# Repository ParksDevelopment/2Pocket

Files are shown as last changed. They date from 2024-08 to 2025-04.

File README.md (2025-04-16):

# 2Pocket

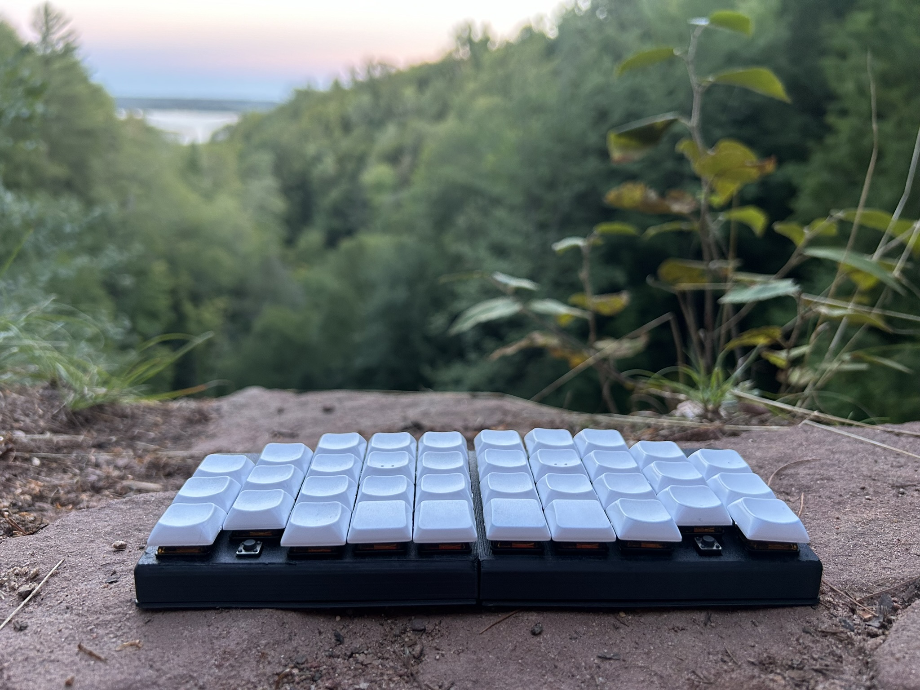
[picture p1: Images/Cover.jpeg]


[Introduction](#Introduction)

[Info and Production](#Production)

[PCB](#PCB)

[Firmware](#Firmware)

[Case](#Case)

[Overview](#Overview)

## Introduciton

The 2Pocket is a pocket keyboard originally created for the [Pocket Keyboard Design Contest](https://chrischrislolo.github.io/orthoLabLogs/pocket-keyboard-design-contest-00.html). As such it was designed to meet the criteria of the contest as closely as possible while still being a practical keyboard for daily use. The feature list of the 2Pocket is pretty fleshed out including:

- 36 Kailh Choc V1 Low Profile Hot swap sockets (Using [Sunset](https://lowprokb.ca/collections/switches/products/sunset-tactile-choc-switches) switches for all pictures)
- Bluetooth support between halves and computer
- Pedometer using a ADXL345 for step counting
- 2 additional 6 mm Push button switches used for bluetooth, step reporting, or any othe KMK key
- Full open source customizeable keymap in KMK. ZMK to be included soon
- 2 3.7V 1100 mAh batteries Charged through the USB C port on the back of each board
- Magnetic casing to make the board unibody for preference, saving space, or travel
- Small enough to fit in your pocket! (according to the contest which gives a 190mm x 76mm x 22mm bounding box with the 2Pocket coming in comfortably at 190mm x 74.8mm x 22mm)

The idea behind the board was to create something that you can put in your pocket, ie fitting the bounding box, but does not force you to make any compromises to your work flow. I work a full time job as an software engineer and use a 36 key layout called [Miryoku](https://github.com/manna-harbour/miryoku_kmk) so it was important to me above all else to fit that standard so 36 keys was a must for me. I am able to hit 85 words per minute on it in monkey type 60 tests which is slower than my peak on a normal keyboard of 100 but definetly far from unpractical. Another key requirement for me was bluetooth. If this would be a pocket board then I would need it to be easier to bring places than my normal keyboard. The size helps but keeping it wireless allows me to pick it up on the way out the door or throw it in my bag without any fear of not having the necessary parts to make it run. Finally I wanted to play into the pocket part of the challenge which lead to the on board ADXL345. If I plan on keeping the board in my pocket It is already in the prime position to track my steps, and by mapping a button press to output my number of steps on the screen I am able to quickly see where I am at on the given day or trip. It gives me a great reason to still carry the board around even if I am not sure it will come in handy. Its not as accurate as a smart watch or even a smartphone but it gets pretty close and I am continuing to improve the step counting algorithem and features.

## Production

I will briefly explain below how to reproduce the board as well as discuss improvements that could be made in the future on the project in each area so. The production of the board is reletively simple, but will require either a 3D printer or ordering the case parts through a provider. I also chose to solder some parts and order the board with other parts soldered on. If you have a soldering station I would recommend you do the same but you can choose whatever works best for you. Below is the parts list which does not inclued the pcb or the case which will be discussed later:

| Part Name  | Quantity | Solder by hand |
|---|---|---|
| Ceramic Capacitors 1uF| 4| NO|
| Tantalum Capacitors 10uF| 2| NO|
| ADXL345 | 2| NO|
| 1N4148 Diode | 38| NO|
| 4.7 k oHm Resistor | 4| NO|
| 2 pin Jst socket | 2| YES|
| 6 mm push button switches | 2| YES|
| Choc hotswap sockets | 36| YES|
| Xiao NRF52840 | 2| YES|
| EEMB Lithium Polymer Battery 3.7V 1100mAh | 2| DNA|

most of these the brand doesn't matter but the case is modeled to fit this specific battery so if you would like to use a different battery you need to make some modifications.

## PCB

The PCB has a footprint of 185mm x 71mm x 1.6mm which does not give a ton of room for the case but it is hard to scale it down much without giving up keys or making the wiring much more complicated. To order the case go to the PCB folder in this repo and then go to the production folder in there. that includes the gerber files as well as the BOM and POS files needed to order from jlcpbc. The original kicad project is there as well so if you need to regenerate the files that should be possible. the BOM will only inclued the parts I list as not soldered by hand. in addition double check the position of the ADXL345s. they should always be oriented so pin one is on the side closer to the Xiao board. Once the board is ordered just snap it in the middle and trim off any parts left over on the side. Then solder the remaining part on. 

I am pretty happy with the pcb but there are 2 big changes I would make:

1. I would wire the ncf pins on the xiao to the interupt pins on the adxl345. The ncf pins can act as extra gpio pins with some software changes and connecting them to the adxl345 would let me do things like shake to undo or stop any keystrokes if it detects the board has been knocked off. this stuff could still be done as is but I would need to check often and it would hurt the battery.
2. I could include a coulple mounting holes. I got by ok without them but some holes that are purely for helping connect it to the case would open up how you can design the case quite a bit.

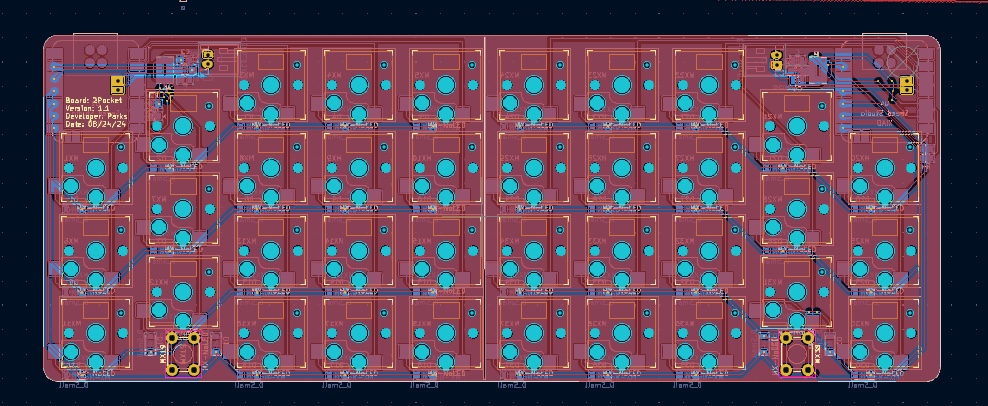
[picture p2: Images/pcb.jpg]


## Firmware

The firmware is written in KMK. To install it just follow the [getting started](https://kmkfw.io/Getting_Started/) guide on the KMK site. After getting circuit python and kmk installed you should then follow the [bluetooth guide](https://kmkfw.io/ble_hid/) just up to adding the adafruit bluetooth folder into your project. Once that is done you can go to this repo, go to firmware, go to kmk and replace your code.py with the one there then take the adxl345.py and drag it into the extensions folder. Currently the keymap is Miryoku modified which used colemak DH mod. Once all that is done you can edit the keymap to your liking using KC.STEPS to print out how many steps have been taken and KC.CLEARBT to disconnect and pair to a new bluetooth device. kmk bluetooth can be finicky so if you run into issues you can ask at the [zmk help forum](https://kmkfw.zulipchat.com/#recent).

There is a lot I would touch on with the firmware, like I want to flesh out the step counter to keep the number in memory between shutting off so you don't lose it if the battery dies but the number one thing I will add is zmk support. I tried to have this done for the entry date for the contest and am very close but am having trouble getting the adxl345 to interface with zmk. once that is done I will add the zmk firmware here. zmk handles bluetooth much better than kmk so that alone would be worth it. 

## Case

The case is printed in 4 parts and requires a couple parts after the fact. It is pretty bare bones without a lot of bells and whistles due to only having about 5 mm to work with at most. That said it is sturdy enough to go in your pocket and has no gaps save for the usbc port to prevent dust or other things from getting into the board from your pocket. The parts needed are in the table below. I am linking to the ones I used but anything with these dimensions will work. or you can edit the case to fit something else. (I have no idea how affiliated links work but nothing I link to in this page has any affiliation with me and I don't benifit from)

| Part Name  | Quantity | Link  |
|---|---|---|
| Magnets | 8| [Link](https://www.amazon.com/dp/B0936M3WPK?ref=ppx_yo2ov_dt_b_fed_asin_title)|
| M3 threaded inserts| 4| [Link](https://www.amazon.com/dp/B0BQJ6CRNJ?ref=ppx_yo2ov_dt_b_fed_asin_title)|
| M3 flat head screws. shorter the better | 4| [Link](https://www.amazon.com/HanTof-Countersunk-Machine-Wrenches-Threaded/dp/B0B9HWVV61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)|

The top of the case has 2 small holes on the side that is flat and would touch the other half of the keyboard. In both those holes insert the magnets so they are flush and then glue the backs of them around the hole on the inside of the case. Repeat of the other half and let sit.

The bottom half has One set of holes near the battery holder and one set on the other side of the case. The set on the side with the battery holder will hold the magnets. Put some glue at the back and then insert them. The other set of holes need the threaded inserts inside. I use a soldering iron with a M3 tip but you can use any method you would like. 

To combine everything put some keys in the top, push the pcb into the case so the keys go into the hot swap sockets. Then take the bottom, put the battery in the holder and connect it to the jst connector. Then put the bottom on, the magnets should line it all up. Finally screen in the m3 screws on the other side untill they are flush.

The case could be improved in a lot of areas. I have very limited experience with 3D modeling so I have no doubt it can be done much better. I would probably redesign it once I have mounting holes to screw in from the bottom so I don't have to sacrifice the sides so much just to allow for a connection. This is the first part I would do a complete overhaul on but for now it works well enough, keeping the board and battery secure while staying within the bounding box, barely.

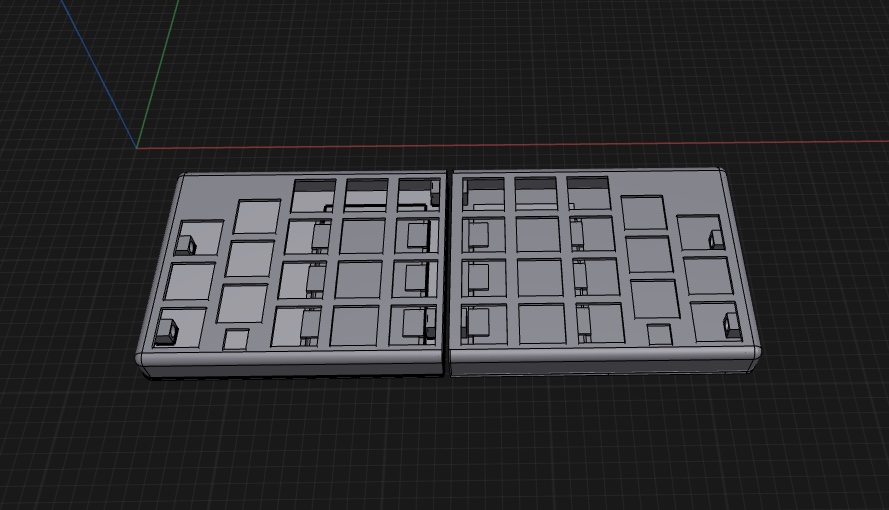
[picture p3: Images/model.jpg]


## Overview

Overall I am very happy with the board and think it fit the criteria of the contest while being a practical board for me to use. The extra gimmick of acting as a pedometer only adds to the charm and my enjoyment of bringing it out of the house. I am excited to keep interating on it in the future but know the board as it stands is fully functional and will be used as my daily driver for a couple days to prove that. I also want to thank Chris Lo aka sporewoh for putting on the contest. It was very fun to design the project fitting into a certain critera and being pushed to add gimmicks and functionality into such small size.

If you enjoyed or found and of the information helpful consider [Buying me a coffee](https://buymeacoffee.com/parks) to keep working on projects like this!

p.s. enjoy the [extra photos](https://photos.app.goo.gl/FVwNr18BBK3Yw1VW6) my wife took of the board on a hike



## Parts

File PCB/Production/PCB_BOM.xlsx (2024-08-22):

Comment | Designator | Footprint
4.7_Resistor | R3,R2,R1,R4 | R_0805_2012Metric
D_Small | D36,D8,D25,D27,D12,D1,D6,D9,D24,D38,D35,D20,D28,D19,D13,D23,D3,D17,D15,D34,D32,D18,D4,D21,D29,D16,D33,D30,D7,D37,D11,D2,D26,D22,D5,D10,D14,D31 | D_SOD-123
T491A106K016AT | C6,C3 | CP_EIA-3216-18_Kemet-A
.1uf_C | C5,C2,C4,C1 | C_0805_2012Metric
ADXL345 | U1,U3 | PQFN80P500X300X100-14N

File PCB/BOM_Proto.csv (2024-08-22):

Id | Designator | Footprint | Quantity | Designation | Supplier and ref
1 | MX12,MX6,MX15,MX31,MX27,MX5,MX11,MX29,MX16,MX2,MX10,MX30,MX34,MX3,MX21,MX20,MX7,MX32,MX13,MX35,MX33,MX25,MX14,MX1,MX8,MX37,MX28,MX9,MX23,MX36,MX17,MX18,MX4,MX24,MX22,MX26 | Kailh_socket_PG1350 | 36 | MX-NoLED
2 | MX19,MX38 | SW_PUSH_6mm | 2 | MX-NoLED
3 | D36,D8,D25,D27,D12,D1,D6,D9,D24,D38,D35,D20,D28,D19,D13,D23,D3,D17,D15,D34,D32,D18,D4,D21,D29,D16,D33,D30,D7,D37,D11,D2,D26,D22,D5,D10,D14,D31 | D_SOD-123 | 38 | D_Small
4 | J2,J1 | JST_PH_S2B-PH-K_1x02_P2.00mm_Horizontal | 2 | Conn_01x02
5 | C6,C3 | CP_EIA-3216-18_Kemet-A | 2 | C_Polarized_US
6 | C5,C2,C4,C1 | C_0805_2012Metric | 4 | C
7 | U1,U3 | PQFN80P500X300X100-14N | 2 | ADXL345
8 | U2,U4 | XIAO-nRF52840-Sense-14P-2.54-21X17.8MM | 2 | Seeed Studio XIAO nRF52840
9 | R3,R2,R1,R4 | R_0805_2012Metric | 4 | R

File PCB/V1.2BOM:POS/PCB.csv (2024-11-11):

Id | Designator | Footprint | Quantity | Designation | Supplier and ref
1 | MX12,MX6,MX15,MX31,MX27,MX5,MX11,MX29,MX16,MX2,MX10,MX30,MX34,MX3,MX21,MX20,MX7,MX32,MX13,MX35,MX33,MX25,MX14,MX1,MX8,MX37,MX28,MX9,MX23,MX36,MX17,MX18,MX4,MX24,MX22,MX26 | Kailh_socket_PG1350 | 36 | MX-NoLED
2 | MX19,MX38 | SW_PUSH_6mm | 2 | MX-NoLED
3 | J3,J4 | PinHeader_1x02_P2.54mm_Vertical | 2 | Conn_01x02
4 | D36,D8,D25,D27,D12,D1,D6,D9,D24,D38,D35,D20,D28,D19,D13,D23,D3,D17,D15,D34,D32,D18,D4,D21,D29,D16,D33,D30,D7,D37,D11,D2,D26,D22,D5,D10,D14,D31 | D_SOD-123 | 38 | D_Small
5 | J2,J1 | JST_PH_S2B-PH-K_1x02_P2.00mm_Horizontal | 2 | Conn_01x02
6 | C6,C3 | CP_EIA-3216-18_Kemet-A | 2 | C_Polarized_US
7 | D39 | D_SOD-123 | 1 | D_Schottky
8 | C5,C2,C4,C1 | C_0805_2012Metric | 4 | C
9 | U1,U3 | PQFN80P500X300X100-14N | 2 | ADXL345
10 | R3,R2,R1,R4 | R_0805_2012Metric | 4 | R
11 | U2,U4 | XIAO-nRF52840-Sense-14P-2.54-21X17.8MM | 2 | Seeed Studio XIAO nRF52840

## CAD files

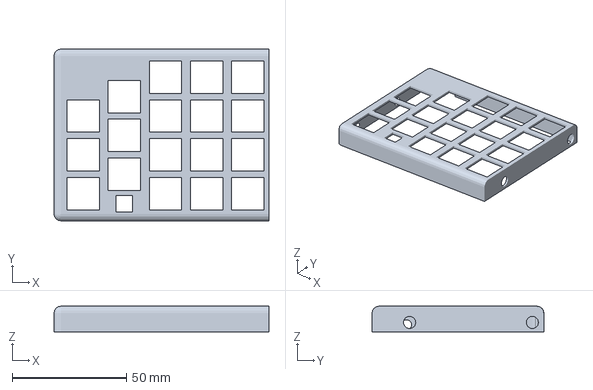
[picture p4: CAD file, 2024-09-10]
Case/Current Case/LeftTop.3mf
94.0 x 75.1 x 11.2 mm

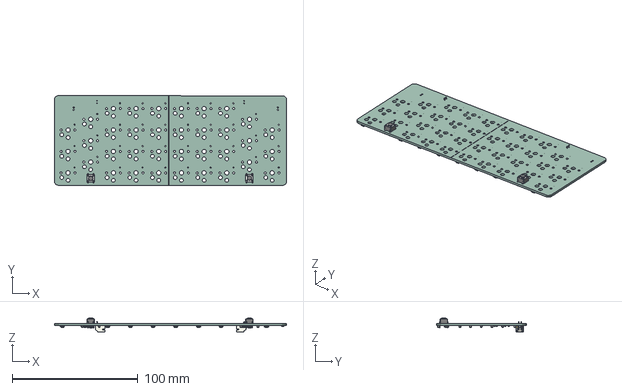
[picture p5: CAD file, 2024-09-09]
Case/PCB_Model.STEP
184.2 x 71.2 x 10.8 mm
PCB PCB

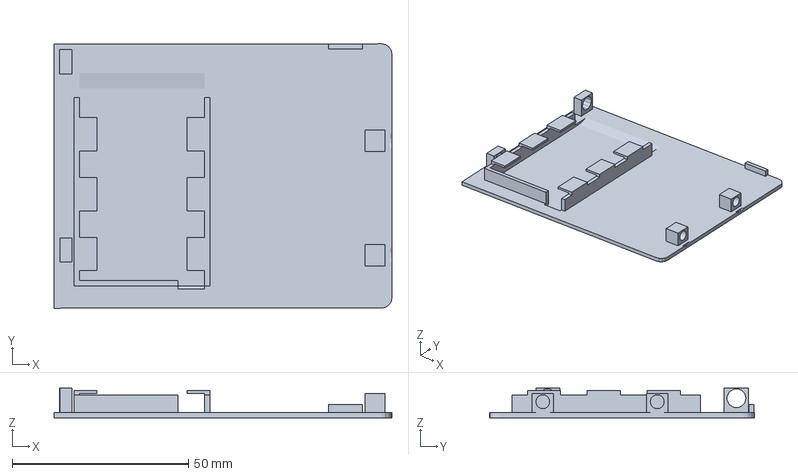
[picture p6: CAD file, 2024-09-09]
Case/Current Case/RightBottom.3mf
96.0 x 75.1 x 8.50 mm

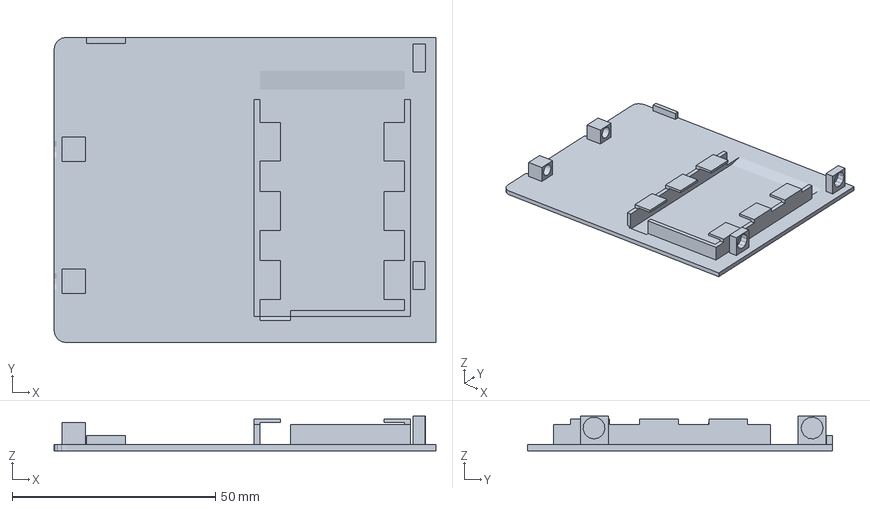
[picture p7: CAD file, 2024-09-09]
Case/Current Case/LeftBottom.3mf
94.0 x 75.1 x 8.50 mm

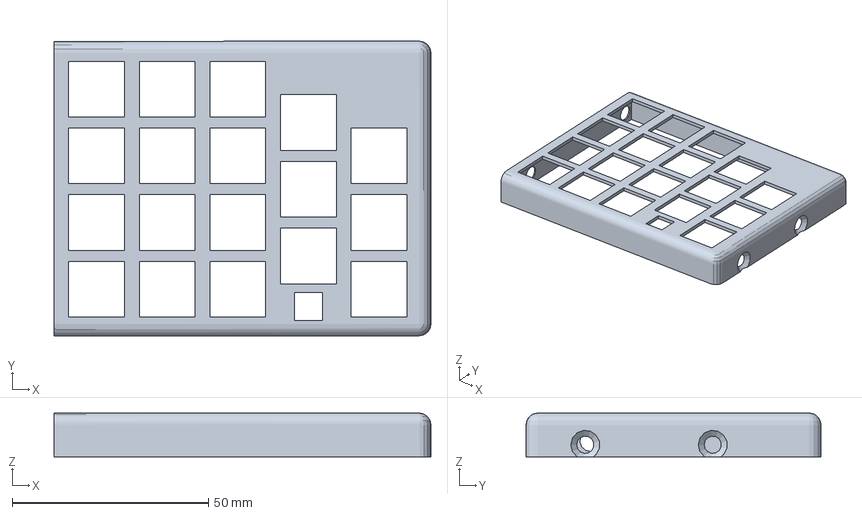
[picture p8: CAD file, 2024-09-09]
Case/Current Case/RightTop.3mf
96.1 x 75.1 x 11.2 mm

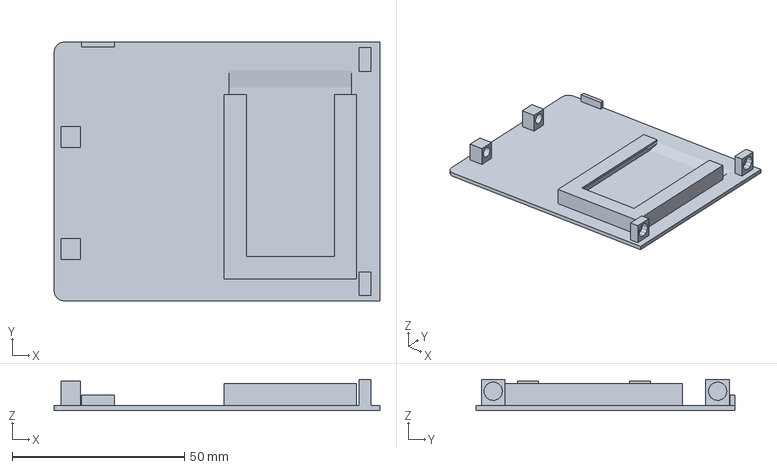
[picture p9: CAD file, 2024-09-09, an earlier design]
Case/Previous Case Revisions/Case_Bottom_4.3mf
94.5 x 75.1 x 9.00 mm

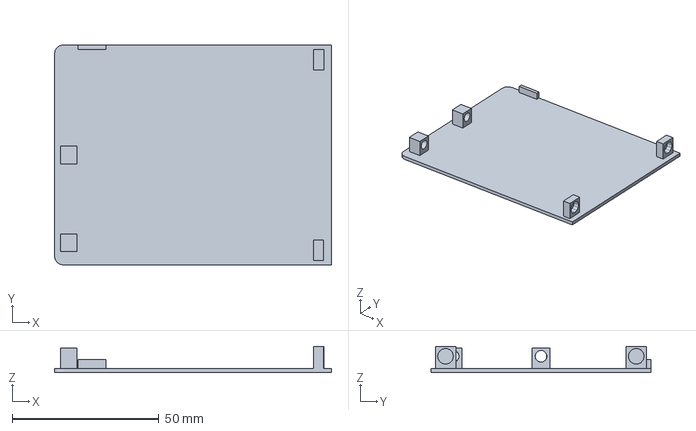
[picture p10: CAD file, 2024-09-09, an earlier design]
Case/Previous Case Revisions/Case_Bottom_3.3mf
94.5 x 75.1 x 9.00 mm

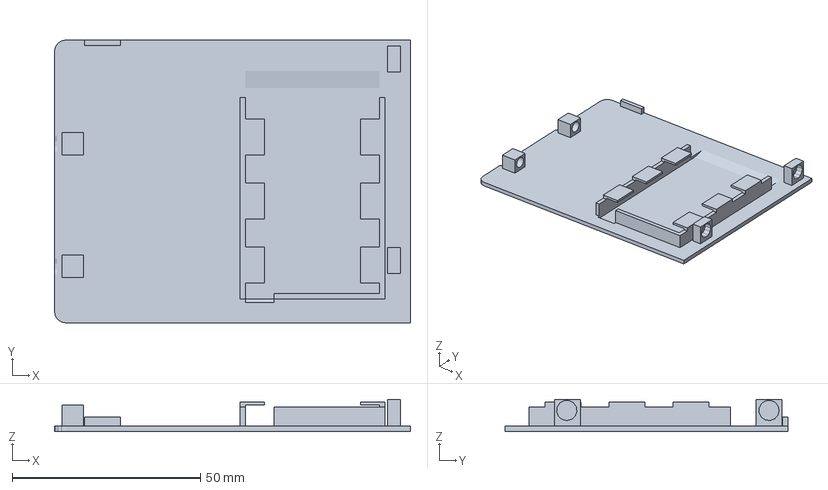
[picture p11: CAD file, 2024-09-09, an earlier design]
Case/Previous Case Revisions/Case_Bottom_6.3mf
94.5 x 75.1 x 8.50 mm

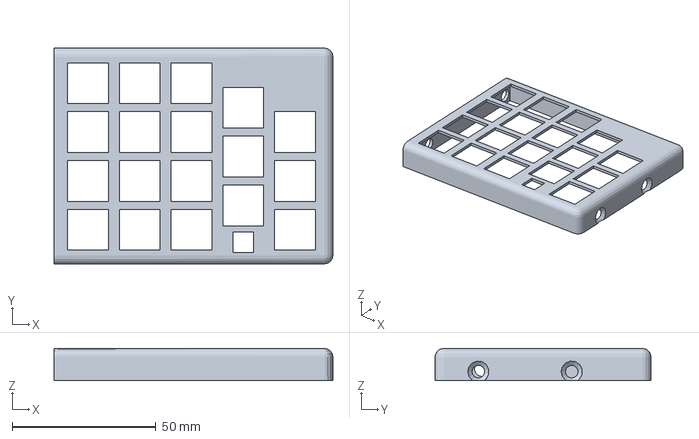
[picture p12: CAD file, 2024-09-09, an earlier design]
Case/Previous Case Revisions/Case_Right_1.3mf
97.1 x 75.1 x 11.2 mm

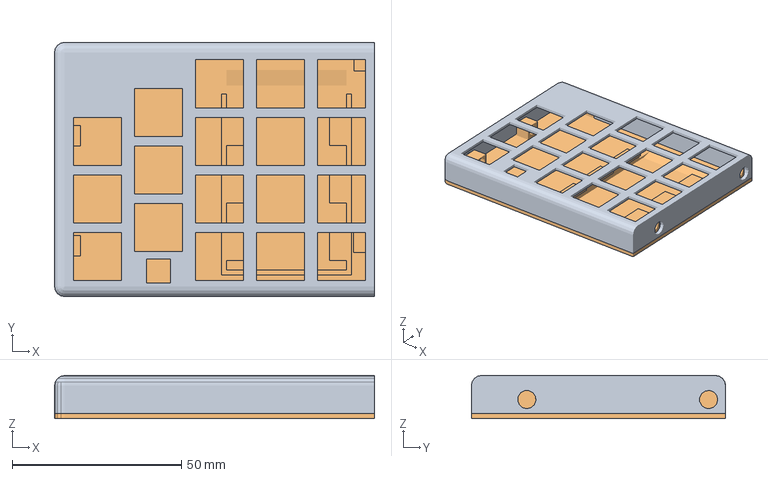
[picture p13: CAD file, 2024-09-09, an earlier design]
Case/Previous Case Revisions/Case_joined_1.3mf
94.5 x 75.1 x 12.7 mm

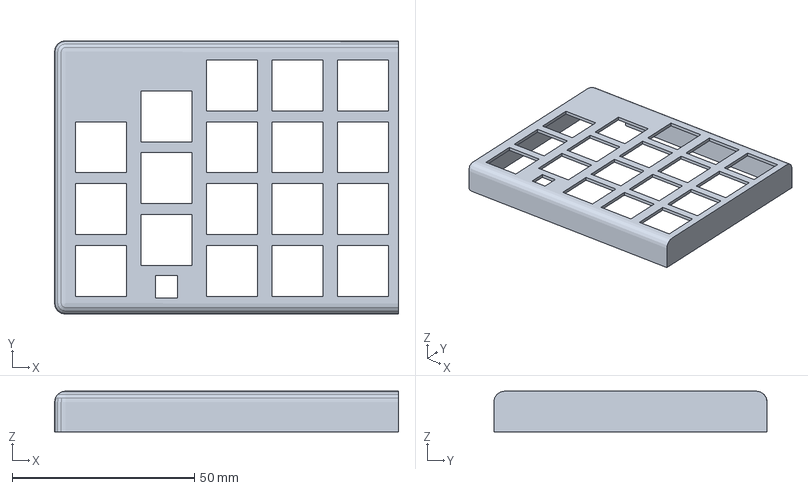
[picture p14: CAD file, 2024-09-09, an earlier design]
Case/Previous Case Revisions/Case_1.3mf
94.5 x 75.1 x 11.2 mm

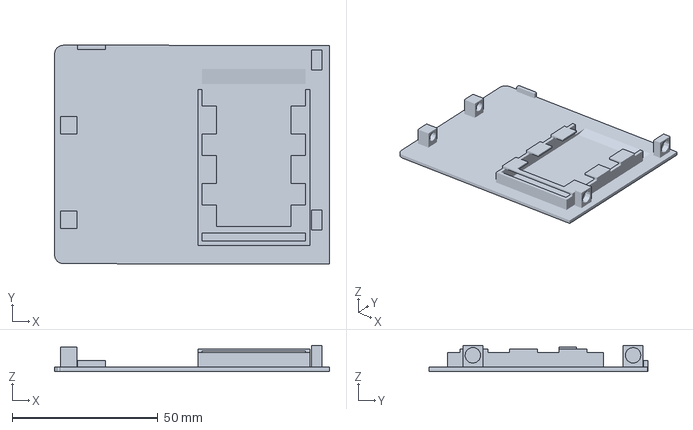
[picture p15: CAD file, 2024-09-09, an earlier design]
Case/Previous Case Revisions/Case_Bottom_5.3mf
94.5 x 75.1 x 9.00 mm

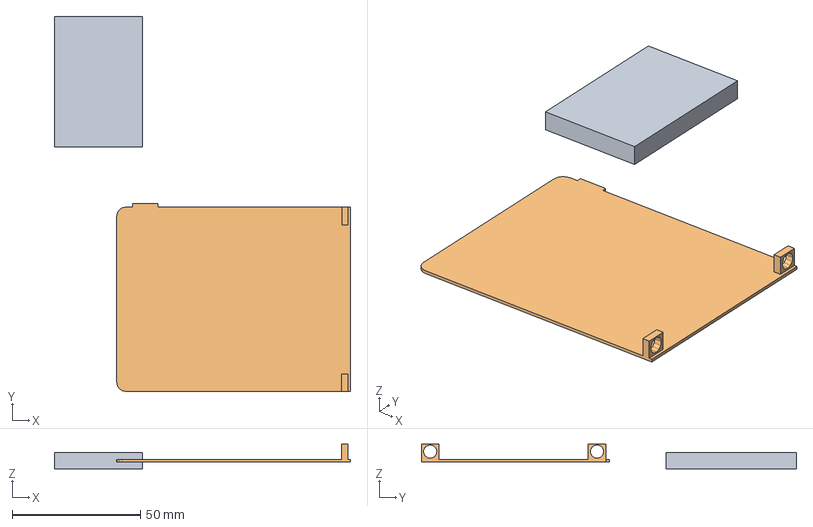
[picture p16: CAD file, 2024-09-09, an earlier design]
Case/Previous Case Revisions/Case_Bottom_1.3mf
115.7 x 146.3 x 9.60 mm

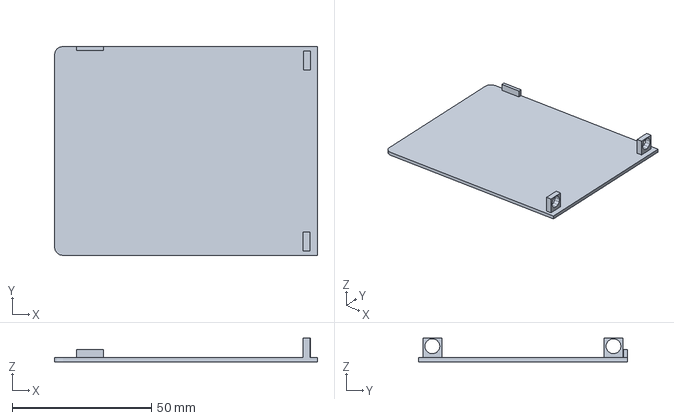
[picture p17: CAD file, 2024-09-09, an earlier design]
Case/Previous Case Revisions/Case_Bottom_2.3mf
94.5 x 75.1 x 8.50 mm

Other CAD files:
Case/Previous Case Revisions/Case_4.3mf
Case/Previous Case Revisions/Case_3.3mf
Case/Previous Case Revisions/Case_2.3mf
Case/Previous Case Revisions/Case_6.3mf
Case/Previous Case Revisions/Case_5.3mf

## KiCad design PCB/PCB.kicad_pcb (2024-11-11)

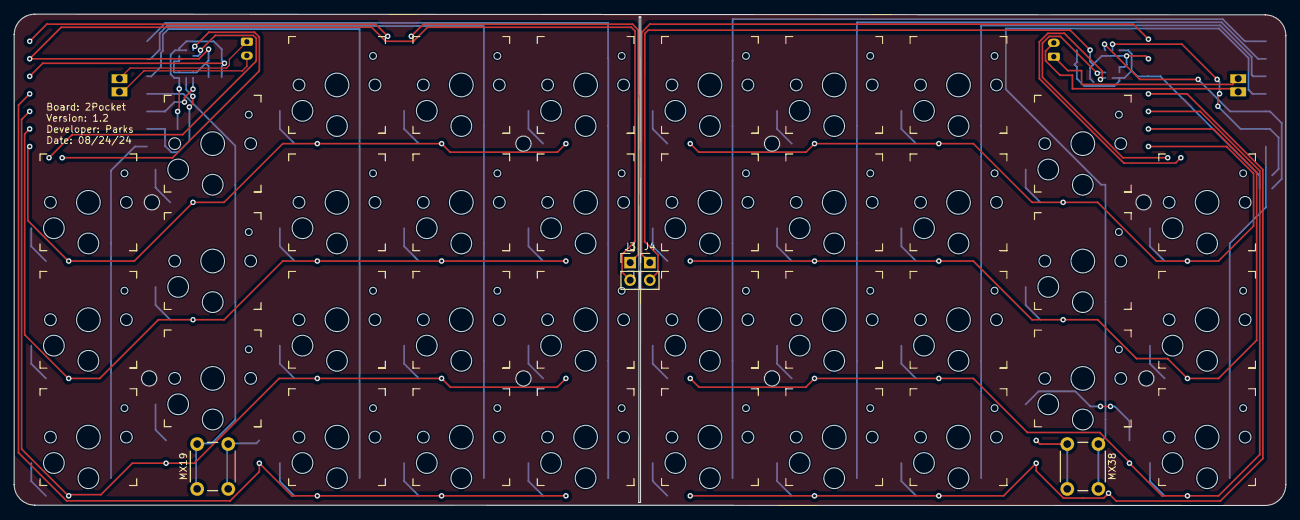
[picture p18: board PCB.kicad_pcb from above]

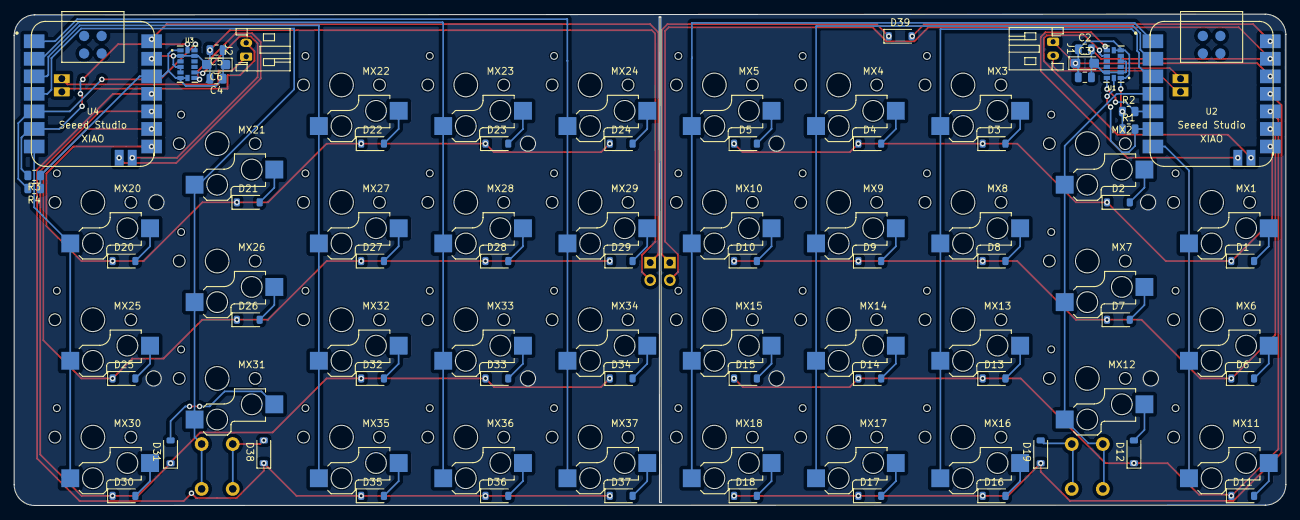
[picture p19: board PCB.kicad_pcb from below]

Board: 2 copper layers, 184.2 x 71.2 mm, 95 parts (55 on the bottom side), 75 nets.

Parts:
C1, C2, C4, C5: C; C_0805_2012Metric
C3, C6: C_Polarized_US; CP_EIA-3216-18_Kemet-A
D1, D2, D3, D4, D5, D6, D7, D8, D9, D10, D11, D12, D13, D14, D15, D16, D17, D18, D19, D20, D21, D22, D23, D24, D25, D26, D27, D28, D29, D30, D31, D32, D33, D34, D35, D36, D37, D38: D_Small; D_SOD-123
D39: D_Schottky; D_SOD-123
J1, J2: Conn_01x02; JST_PH_S2B-PH-K_1x02_P2.00mm_Horizontal
J3, J4: Conn_01x02; PinHeader_1x02_P2.54mm_Vertical
MX1, MX2, MX3, MX4, MX5, MX6, MX7, MX8, MX9, MX10, MX11, MX12, MX13, MX14, MX15, MX16, MX17, MX18, MX20, MX21, MX22, MX23, MX24, MX25, MX26, MX27, MX28, MX29, MX30, MX31, MX32, MX33, MX34, MX35, MX36, MX37: MX-NoLED; Kailh_socket_PG1350
MX19, MX38: MX-NoLED; SW_PUSH_6mm
R1, R2, R3, R4: R; R_0805_2012Metric
U1, U3: ADXL345; PQFN80P500X300X100-14N
U2, U4: Seeed Studio XIAO nRF52840; XIAO-nRF52840-Sense-14P-2.54-21X17.8MM

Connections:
+3.3V: C1.1, C2.1, C3.1, R1.1, R2.1, U1.1 (VDD_I/O), U1.6 (VS), U1.7 (~CS), U2.12 (3V3)
+3.3VA: C4.1, C5.1, C6.1, R3.1, R4.1, U3.1 (VDD_I/O), U3.6 (VS), U3.7 (~CS), U4.12 (3V3)
+5V: D39.2 (A), U2.14 (5V)
+5VA: J4.1, U4.14 (5V)
/Bat+: J1.2, U2.22 (BAT+)
/Bat+B: J2.2, U4.22 (BAT+)
/Bat-: J1.1, U2.21 (BAT-)
/Bat-B: J2.1, U4.21 (BAT-)
/Col0: MX1.1 (COL), MX6.1 (COL), MX11.1 (COL), U2.7 (P1.11_D6_TX)
/Col0B: MX20.1 (COL), MX25.1 (COL), MX30.1 (COL), U4.7 (P1.11_D6_TX)
/Col1: MX2.1 (COL), MX7.1 (COL), MX12.1 (COL), MX19.1 (COL), U2.4 (P0.29_A3_D3)
/Col1B: MX21.1 (COL), MX26.1 (COL), MX31.1 (COL), MX38.1 (COL), U4.4 (P0.29_A3_D3)
/Col2: MX3.1 (COL), MX8.1 (COL), MX13.1 (COL), MX16.1 (COL), U2.3 (P0.28_A2_D2)
/Col2B: MX22.1 (COL), MX27.1 (COL), MX32.1 (COL), MX35.1 (COL), U4.3 (P0.28_A2_D2)
/Col3: MX4.1 (COL), MX9.1 (COL), MX14.1 (COL), MX17.1 (COL), U2.2 (P0.03_A1_D1)
/Col3B: MX23.1 (COL), MX28.1 (COL), MX33.1 (COL), MX36.1 (COL), U4.2 (P0.03_A1_D1)
/Col4: MX5.1 (COL), MX10.1 (COL), MX15.1 (COL), MX18.1 (COL), U2.1 (P0.02_A0_D0)
/Col4B: MX24.1 (COL), MX29.1 (COL), MX34.1 (COL), MX37.1 (COL), U4.1 (P0.02_A0_D0)
/I1: U1.8 (INT1), U2.19 (P0.09_NFC1)
/I1B: U3.8 (INT1), U4.19 (P0.09_NFC1)
/I2: U1.9 (INT2), U2.20 (P0.10_NFC2)
/I2B: U3.9 (INT2), U4.20 (P0.10_NFC2)
/Row0: D1.1 (K), D2.1 (K), D3.1 (K), D4.1 (K), D5.1 (K), U2.8 (P1.12_D7_RX)
/Row0B: D20.1 (K), D21.1 (K), D22.1 (K), D23.1 (K), D24.1 (K), U4.8 (P1.12_D7_RX)
/Row1: D6.1 (K), D7.1 (K), D8.1 (K), D9.1 (K), D10.1 (K), U2.9 (P1.13_D8_SCK)
/Row1B: D25.1 (K), D26.1 (K), D27.1 (K), D28.1 (K), D29.1 (K), U4.9 (P1.13_D8_SCK)
/Row2: D11.1 (K), D12.1 (K), D13.1 (K), D14.1 (K), D15.1 (K), U2.10 (P1.14_D9_MISO)
/Row2B: D30.1 (K), D31.1 (K), D32.1 (K), D33.1 (K), D34.1 (K), U4.10 (P1.14_D9_MISO)
/Row3: D16.1 (K), D17.1 (K), D18.1 (K), D19.1 (K), U2.11 (P1.15_D10_MOSI)
/Row3B: D35.1 (K), D36.1 (K), D37.1 (K), D38.1 (K), U4.11 (P1.15_D10_MOSI)
/SCL: R1.2, U1.14 (SCL/SCLK), U2.6 (P0.05_A5_D5_SCL)
/SCLB: R3.2, U3.14 (SCL/SCLK), U4.6 (P0.05_A5_D5_SCL)
/SDA: R2.2, U1.13 (SDA/SDI/SDIO), U2.5 (P0.04_A4_D4_SDA)
/SDAB: R4.2, U3.13 (SDA/SDI/SDIO), U4.5 (P0.04_A4_D4_SDA)
GND: C1.2, C2.2, C3.2, J3.2, U1.2 (GND), U1.4 (GND), U1.5 (GND), U1.12 (SDO/ALT_ADDRESS), U2.13 (GND)
GND1: C4.2, C5.2, C6.2, J4.2, U3.2 (GND), U3.4 (GND), U3.5 (GND), U3.12 (SDO/ALT_ADDRESS), U4.13 (GND)
unnamed: D1.2 (A), MX1.2 (ROW)
unnamed: D2.2 (A), MX2.2 (ROW)
unnamed: D3.2 (A), MX3.2 (ROW)
unnamed: D4.2 (A), MX4.2 (ROW)
unnamed: D5.2 (A), MX5.2 (ROW)
unnamed: D6.2 (A), MX6.2 (ROW)
unnamed: D7.2 (A), MX7.2 (ROW)
unnamed: D8.2 (A), MX8.2 (ROW)
unnamed: D9.2 (A), MX9.2 (ROW)
unnamed: D10.2 (A), MX10.2 (ROW)
unnamed: D11.2 (A), MX11.2 (ROW)
unnamed: D12.2 (A), MX12.2 (ROW)
unnamed: D13.2 (A), MX13.2 (ROW)
unnamed: D14.2 (A), MX14.2 (ROW)
unnamed: D15.2 (A), MX15.2 (ROW)
unnamed: D16.2 (A), MX16.2 (ROW)
unnamed: D17.2 (A), MX17.2 (ROW)
unnamed: D18.2 (A), MX18.2 (ROW)
unnamed: D19.2 (A), MX19.2 (ROW)
unnamed: D20.2 (A), MX20.2 (ROW)
unnamed: D21.2 (A), MX21.2 (ROW)
unnamed: D22.2 (A), MX22.2 (ROW)
unnamed: D23.2 (A), MX23.2 (ROW)
unnamed: D24.2 (A), MX24.2 (ROW)
unnamed: D25.2 (A), MX25.2 (ROW)
unnamed: D26.2 (A), MX26.2 (ROW)
unnamed: D27.2 (A), MX27.2 (ROW)
unnamed: D28.2 (A), MX28.2 (ROW)
unnamed: D29.2 (A), MX29.2 (ROW)
unnamed: D30.2 (A), MX30.2 (ROW)
unnamed: D31.2 (A), MX31.2 (ROW)
unnamed: D32.2 (A), MX32.2 (ROW)
unnamed: D33.2 (A), MX33.2 (ROW)
unnamed: D34.2 (A), MX34.2 (ROW)
unnamed: D35.2 (A), MX35.2 (ROW)
unnamed: D36.2 (A), MX36.2 (ROW)
unnamed: D37.2 (A), MX37.2 (ROW)
unnamed: D38.2 (A), MX38.2 (ROW)
unnamed: D39.1 (K), J3.1

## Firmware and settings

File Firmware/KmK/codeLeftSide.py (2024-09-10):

print("Starting")


import busio
import board
from kmk.kmk_keyboard import KMKKeyboard; keyboard = KMKKeyboard()
from kmk.keys import KC, make_key
from kmk.scanners import DiodeOrientation
from kmk.modules.split import Split, SplitType, SplitSide
from kmk.modules.layers import Layers; keyboard.modules.append(Layers())
from kmk.modules.holdtap import HoldTap; keyboard.modules.append(HoldTap())
from kmk.modules.tapdance import TapDance; keyboard.modules.append(TapDance())
from kmk.extensions.adxl345 import adxl345
from kmk.modules.macros import Macros

from kmk.hid import HIDModes
from kmk.hid import BLEHID


from kmk.handlers.stock import passthrough
macros = Macros()
keyboard.modules.append(macros)

adxl = adxl345()
keyboard.modules.append(adxl)

def stepReport(*args, **kwargs):
    temp = "You have walked: " + str(adxl.steps)
    print(temp) #print to serial console
    keyboard.tap_key(KC.MACRO(repr(temp)+" ")) #type it on keyboard

make_key(names=('STEPS',), on_press=stepReport, on_release=passthrough)

bluetoothInterface = BLEHID()
def BT(*args, **kwargs):
    bluetoothInterface.clear_bonds()
    bluetoothInterface.start_advertising()

make_key(names=('CLEARBT',), on_press=BT, on_release=passthrough)

keyboard.col_pins = (board.D6, board.D3, board.D2, board.D1, board.D0,)
keyboard.row_pins = (board.D7, board.D8, board.D9, board.D10,)
keyboard.diode_orientation = DiodeOrientation.COL2ROW

split = Split(
    split_flip=True,  # If both halves are the same, but flipped, set this True
    split_side=None,  # Sets if this is to SplitSide.LEFT or SplitSide.RIGHT, or use EE hands
    split_type=SplitType.BLE,  # Defaults to UART
)
keyboard.modules.append(split)


keyboard.keymap = [
# BASE
[
KC.Q, KC.W, KC.F, KC.P, KC.B, KC.J, KC.L, KC.U, KC.Y, KC.QUOT,
KC.HT(KC.A, KC.LGUI, prefer_hold=False, tap_interrupted=True, tap_time=200), KC.HT(KC.R, KC.LALT, prefer_hold=False, tap_interrupted=True, tap_time=200), KC.HT(KC.S, KC.LCTL, prefer_hold=False, tap_interrupted=True, tap_time=200), KC.HT(KC.T, KC.LSFT, prefer_hold=False, tap_interrupted=True, tap_time=200), KC.G, KC.M, KC.HT(KC.N, KC.LSFT, prefer_hold=False, tap_interrupted=True, tap_time=200), KC.HT(KC.E, KC.LCTL, prefer_hold=False, tap_interrupted=True, tap_time=200), KC.HT(KC.I, KC.LALT, prefer_hold=False, tap_interrupted=True, tap_time=200), KC.HT(KC.O, KC.LGUI, prefer_hold=False, tap_interrupted=True, tap_time=200),
KC.Z, KC.HT(KC.X, KC.RALT, prefer_hold=False, tap_interrupted=True, tap_time=200), KC.C, KC.D, KC.V, KC.K, KC.H, KC.COMM, KC.HT(KC.DOT, KC.RALT, prefer_hold=False, tap_interrupted=True, tap_time=200), KC.SLSH,
KC.NO, KC.CLEARBT, KC.ESC, KC.LT(1, KC.SPC, prefer_hold=True, tap_interrupted=False, tap_time=200), KC.TAB, KC.ENT, KC.LT(2, KC.BSPC, prefer_hold=True, tap_interrupted=False, tap_time=200), KC.DEL
],
# NAV
[
KC.TD(KC.NO, KC.RELOAD, tap_time=200), KC.TD(KC.NO, KC.NO, tap_time=200), KC.TD(KC.NO, KC.NO, tap_time=200), KC.TD(KC.NO, KC.NO, tap_time=200), KC.NO, KC.NO, KC.LSFT(KC.INS), KC.LCTL(KC.INS), KC.LSFT(KC.DEL), KC.NO,
KC.LGUI, KC.LALT, KC.LCTL, KC.LSFT, KC.NO, KC.TD(KC.NO, KC.CAPS, tap_time=200), KC.LEFT, KC.DOWN, KC.UP, KC.RGHT,
KC.NO, KC.RALT, KC.TD(KC.NO, KC.NO, tap_time=200), KC.TD(KC.NO, KC.NO, tap_time=200), KC.NO, KC.INS, KC.HOME, KC.PGDN, KC.PGUP, KC.END,
KC.NO, KC.NO, KC.NO, KC.NO, KC.NO, KC.ENT, KC.BSPC, KC.DEL, KC.NO, KC.NO
],
# NUM
[
KC.LBRC, KC.N7, KC.N8, KC.N9, KC.RBRC, KC.NO, KC.TD(KC.NO, KC.NO, tap_time=200), KC.TD(KC.NO, KC.NO, tap_time=200), KC.TD(KC.NO, KC.NO, tap_time=200), KC.TD(KC.NO, KC.RELOAD, tap_time=200),
KC.SCLN, KC.N4, KC.N5, KC.N6, KC.EQL, KC.NO, KC.LSFT, KC.LCTL, KC.LALT, KC.LGUI,
KC.GRV, KC.N1, KC.N2, KC.N3, KC.BSLS, KC.NO, KC.TD(KC.NO, KC.NO, tap_time=200), KC.TD(KC.NO, KC.NO, tap_time=200), KC.RALT, KC.NO,
KC.NO, KC.STEPS, KC.DOT, KC.N0, KC.MINS, KC.NO, KC.NO, KC.NO, KC.NO, KC.NO
],

]

layer_names_list = [
"Base", "Nav", "Num",
]

if __name__ == '__main__':
    keyboard.go(hid_type=HIDModes.BLE, ble_name='2Pocket')

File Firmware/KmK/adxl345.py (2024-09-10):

import busio
import board
import math

from kmk.extensions import Extension
import adafruit_adxl34x


class adxl345(Extension):
    def __init__(self):
        i2c = busio.I2C(board.SCL, board.SDA)
        accelerometer = adafruit_adxl34x.ADXL345(i2c)
        self.accelerometer = accelerometer
        self.steps = 0
        self.currentstep = math.trunc(self.accelerometer.acceleration[2])

    def on_runtime_enable(self, sandbox):
        return

    def on_runtime_disable(self, sandbox):
        return

    def during_bootup(self, sandbox):
        return

    def before_matrix_scan(self, sandbox):
        #print("X:", math.trunc(self.accelerometer.acceleration[0]), "Y:", math.trunc(self.accelerometer.acceleration[1]), "Z:", math.trunc(self.accelerometer.acceleration[2]), "steps: ", self.steps)
        if(self.currentstep < 1 and math.trunc(self.accelerometer.acceleration[2]) == 3):
            self.steps += 1
            self.currentstep = 3
        elif(self.currentstep > 2 and math.trunc(self.accelerometer.acceleration[2])  == 0):
            self.steps += 1
            self.currentstep = 0

    def after_matrix_scan(self, sandbox):
        return

    def before_hid_send(self, sandbox):
        return

    def after_hid_send(self, sandbox):
        return

    def on_powersave_enable(self, sandbox):
        return

    def on_powersave_disable(self, sandbox):
        return

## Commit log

2024-09-10 Updating for submission
    [Case_1.3mf, Case_2.3mf, Case_3.3mf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]
2024-11-11 1.2 changes for pass through charging and mounting
    [PCB-B_Cu.gbr, PCB-B_Mask.gbr, PCB-B_Paste.gbr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]
